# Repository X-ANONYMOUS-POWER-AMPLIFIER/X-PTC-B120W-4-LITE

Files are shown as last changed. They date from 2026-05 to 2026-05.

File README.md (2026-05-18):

# X-PTC-B120W-4-LITE PROTECTION CIRCUIT FOR X-B120W-4-LITE CLASS-B POWER AMPLIFIER MAIN-CIRCUIT

X-PTC-B120W-4-LITE is a protection circuit module for [X-B120W-4-LITE CLASS-B POWER AMPLIFIER MAIN-CIRCUIT](https://github.com/X-ANONYMOUS-POWER-AMPLIFIER/X-B120W-4-LITE/). It provides both open-circuit and short-circuit protection for protecting both side of the power amplifier main-circuit and the loudspeaker. This circuit is designed to be fit on a small size single-sided PCB and for easy to install.

This X-PTC-B120W-4-LITE is designed to work in 12V DC non-symmetrical operating voltage. None of additional operating voltage is needed. The [X-10A42V-DDSB-PSU PSU module](https://github.com/X-ANONYMOUS-POWER-AMPLIFIER/X-10A42V-DDSB-PSU) is applicable to provide operating voltages for powering-up both [X-B120W-4-LITE CLASS-B POWER AMPLIFIER MAIN-CIRCUIT](https://github.com/X-ANONYMOUS-POWER-AMPLIFIER/X-B120W-4-LITE/) module and this X-PTC-B120W-4-LITE protection module. 

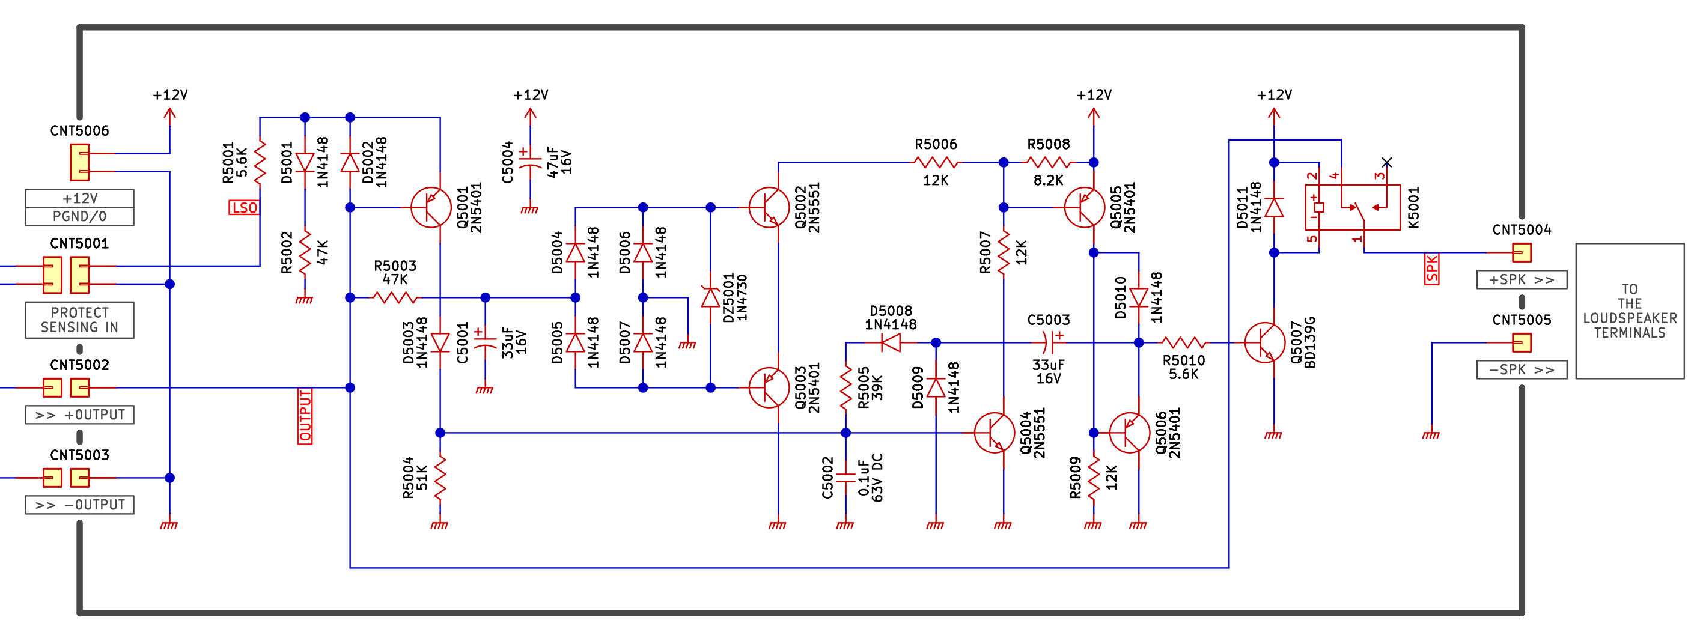
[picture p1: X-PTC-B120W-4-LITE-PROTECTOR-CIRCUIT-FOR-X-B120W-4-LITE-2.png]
X-PTC-B120W-4-LITE schematic diagram


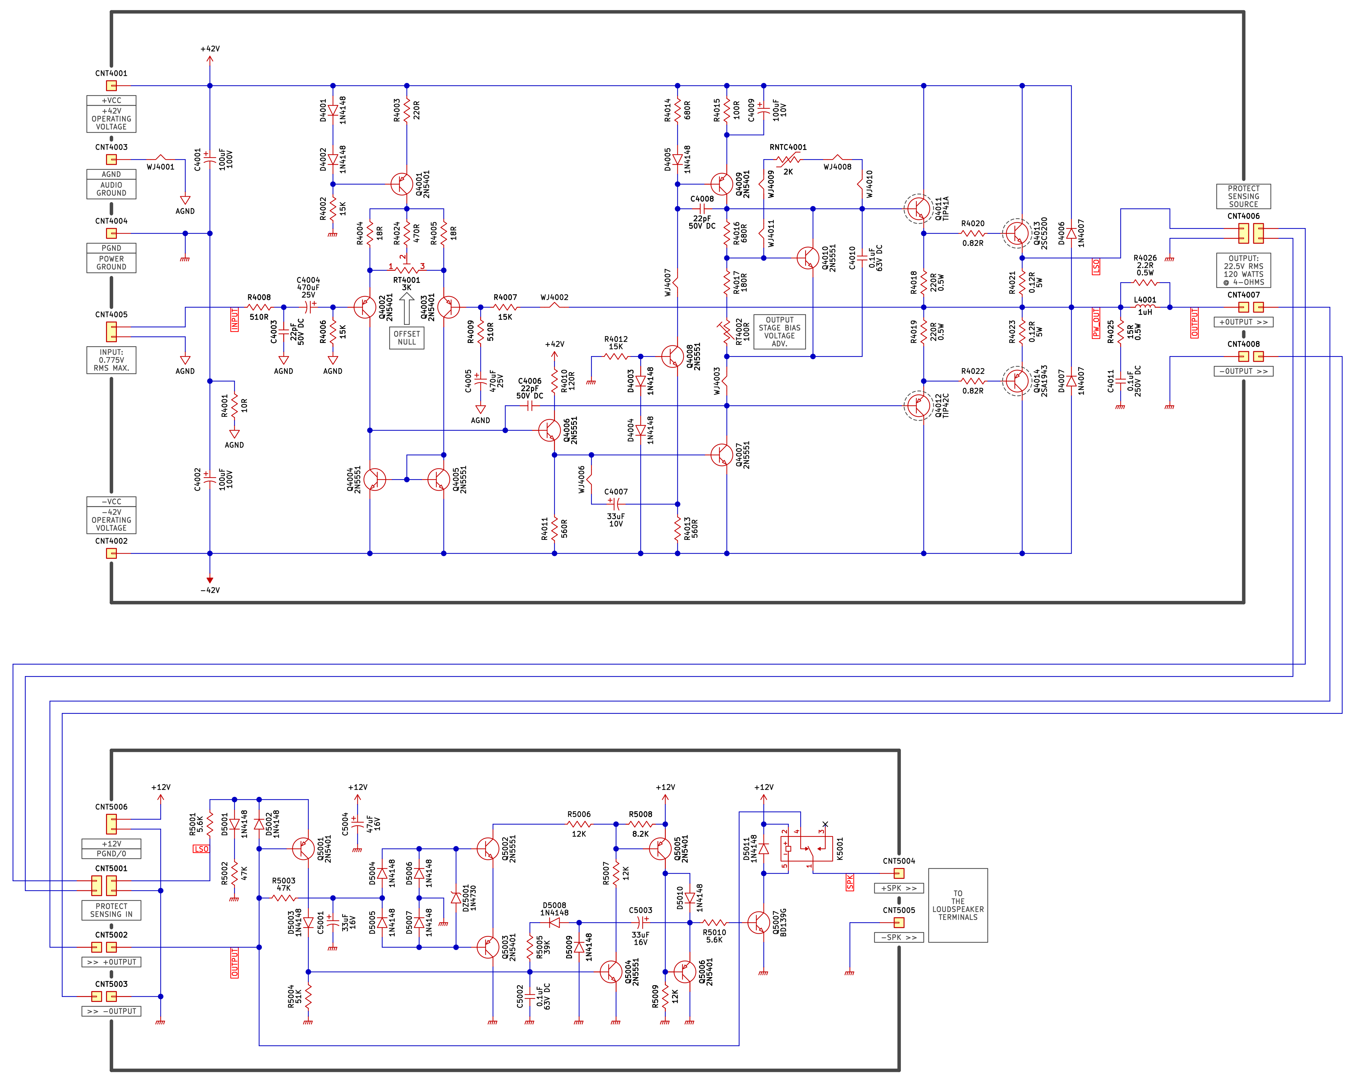
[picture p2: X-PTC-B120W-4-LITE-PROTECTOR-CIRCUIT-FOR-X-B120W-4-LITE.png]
X-PTC-B120W-4-LITE wiring schematic diagram


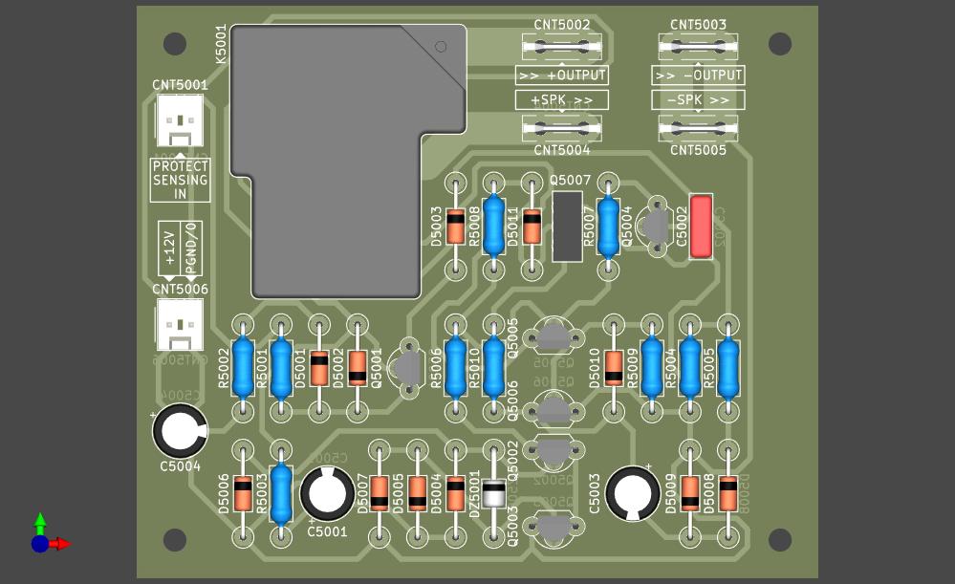
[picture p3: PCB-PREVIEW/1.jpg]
Circuit board preview 1

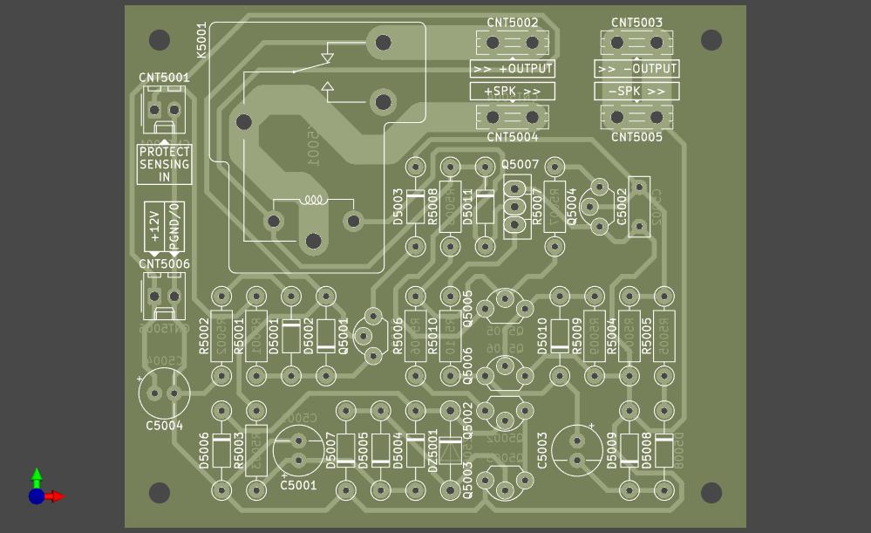
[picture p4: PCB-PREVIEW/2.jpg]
Circuit board preview 2

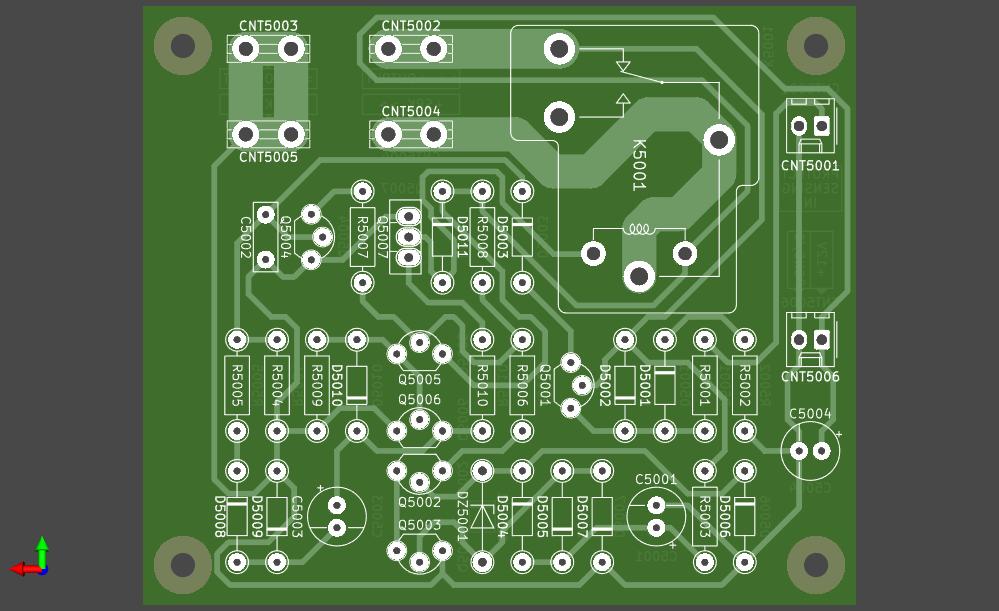
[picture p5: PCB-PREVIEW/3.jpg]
Circuit board preview 3

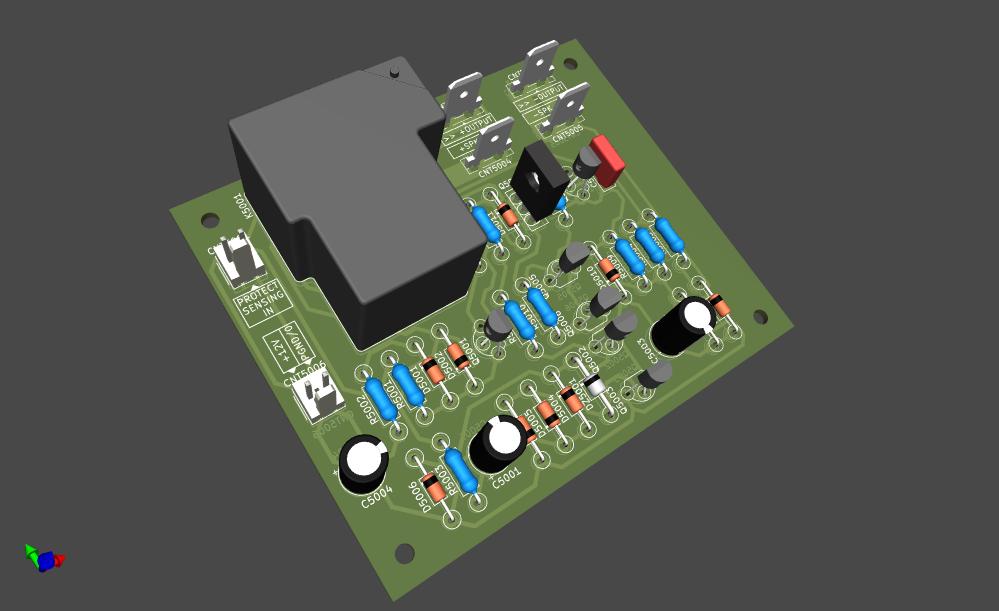
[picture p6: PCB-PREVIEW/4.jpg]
Circuit board preview 4

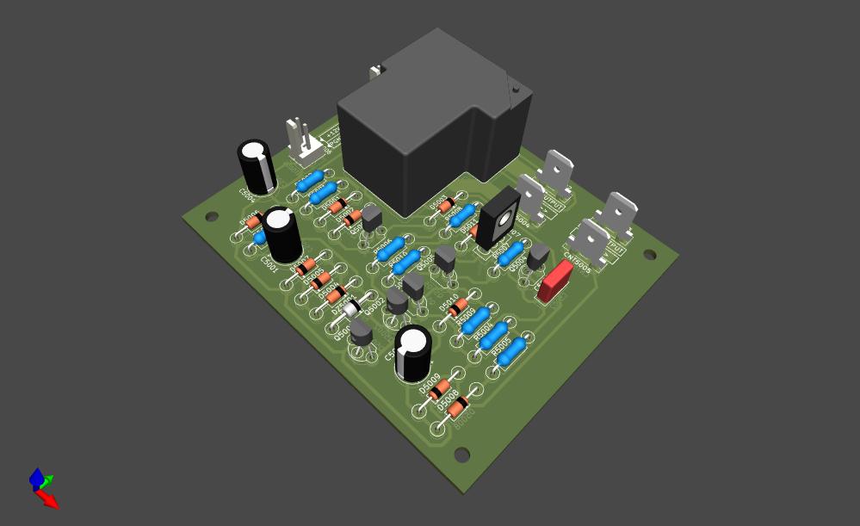
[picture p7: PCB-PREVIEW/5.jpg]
Circuit board preview 5


## License

1. **License Grant**  
The Licensor hereby grants you a worldwide, royalty-free, non-exclusive, perpetual license to use the circuit design for the non-commercial purposes only.
2. **Conditions**  
Attribution: You must provide credit to the original creator when distributing this circuit design.
3. **Disclaimer of Warranty**  
THE DESIGN IS PROVIDED "AS IS". THE LICENSOR MAKES NO WARRANTIES, EXPRESS OR IMPLIED, REGARDING THE DESIGN, INCLUDING BUT NOT LIMITED TO ANY IMPLIED WARRANTIES OF MERCHANTABILITY OR FITNESS FOR A PARTICULAR PURPOSE.
4. **Limitation of Liability**  
IN NO EVENT SHALL THE LICENSOR BE LIABLE FOR ANY DAMAGES, INCLUDING BUT NOT LIMITED TO DIRECT, INDIRECT, INCIDENTAL, OR CONSEQUENTIAL DAMAGES ARISING OUT OF THE USE OF THE DESIGN.

# Design Files Bundle Download

Design files bundle is available for download by follow the URL: [https://github.com/X-ANONYMOUS-POWER-AMPLIFIER/X-PTC-B120W-4-LITE/archive/refs/heads/main.zip](https://github.com/X-ANONYMOUS-POWER-AMPLIFIER/X-PTC-B120W-4-LITE/archive/refs/heads/main.zip)

The main design files of schematic and PCB design are in [KiCad](https://www.kicad.org/) V.9.x format.

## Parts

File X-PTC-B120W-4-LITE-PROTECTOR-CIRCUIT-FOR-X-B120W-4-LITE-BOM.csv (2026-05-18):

Reference | Value | Rating | Description | MFR Number | Manufacturer | Qty
C5001,C5003 | 33uF | 16V | Aluminum Electrolytic Capacitors - Radial Leaded 33uF 16V | ECE-A1CKA330 | Panasonic | 2
C5002 | 0.1uF | 63V DC | Film Capacitors 0.1 uF 63 VDC 5% | MKS2C031001A00JI00 | WIMA | 1
C5004 | 47uF | 16V | Aluminum Electrolytic Capacitors - Radial Leaded 47uF 16V | ECE-A1CKA470 | Panasonic | 1
CNT5001,CNT5006 | 22-27-2021 |  | Headers & Wire Housings 2 POS HEADER | 22-27-2021 | Molex | 2
CNT5002,CNT5003,CNT5004,CNT5005 | 2376582-2 |  | 250 FASTON PCB TAB TPBR | 2376582-2 | TE Connectivity | 4
D5001,D5002,D5003,D5004,D5005,D5006,D5007,D5008,D5009,D5010,D5011 | 1N4148 |  | Small Signal Switching Diodes Small Signal Diode, DO-35, 100V, 0.2A, 175C | 1N4148 | Diotec Semiconductor | 11
DZ5001 | 1N4730 |  | Zener Diodes 3.9 Volt 1.3 Watt | 1N4730A-TAP | Vishay Semiconductors | 1
K5001 | SLA-12VDC-SL-C |  | SUBMINATURE HIGH POWER RELAY 5P | SLA-12VDC-SL-C | Songle Relay | 1
Q5001,Q5003,Q5005,Q5006 | 2N5401 |  | Bipolar Transistors - BJT PNP 160Vcbo 150Vceo 5.0Vebo 600mA 625mW | 2N5401 TIN/LEAD | Central Semiconductor | 4
Q5002,Q5004 | 2N5551 |  | Bipolar Transistors - BJT NPN 180Vcbo 160Vceo 6.0Vebo 600mA 625mW\ | 2N5551 TIN/LEAD | Central Semiconductor | 2
Q5007 | BD139G |  | Bipolar Transistors - BJT 1.5A 80V 12.5W NPN | BD139G | onsemi | 1
R5001,R5010 | 5.6K | 0.25W | Metal Film Resistors - Through Hole 5.6K OHM 1/4W 1% | MFR-25FRE52-5K6 | YAGEO | 2
R5002,R5003 | 47K | 0.25W | Metal Film Resistors - Through Hole 47K OHM 1/4W 1% | MFR-25FRE52-47K | YAGEO | 2
R5004 | 51K | 0.25W | Metal Film Resistors - Through Hole 510 OHM 1/4W 1% | MFR-25FRE52-51K | YAGEO | 1
R5005 | 39K | 0.25W | Metal Film Resistors - Through Hole 39K OHM 1/4W 1% | MFR-25FRE52-39K | YAGEO | 1
R5006,R5007,R5009 | 12K | 0.25W | Metal Film Resistors - Through Hole 12K OHM 1/4W 1% | MFR-25FRE52-12K | YAGEO | 3
R5008 | 8.2K | 0.25W | Metal Film Resistors - Through Hole 8.2K OHM 1/4W 1% | MFR-25FRE52-8K2 | YAGEO | 1

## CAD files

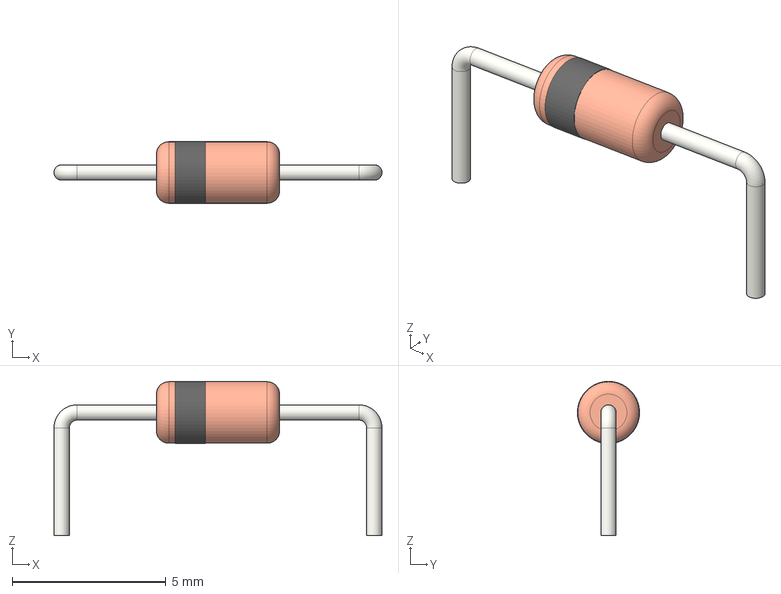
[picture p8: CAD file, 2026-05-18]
3D-FOOTPRINTS/D_DO-35_SOD27_P10.16mm_Horizontal.step
10.7 x 2.02 x 5.01 mm

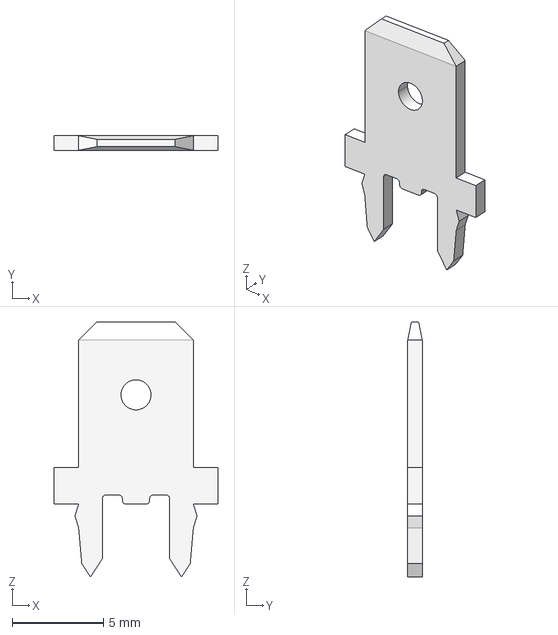
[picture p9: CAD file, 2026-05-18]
3D-FOOTPRINTS/c-2376582-2-a-3d.stp
9.00 x 0.8 x 14.0 mm

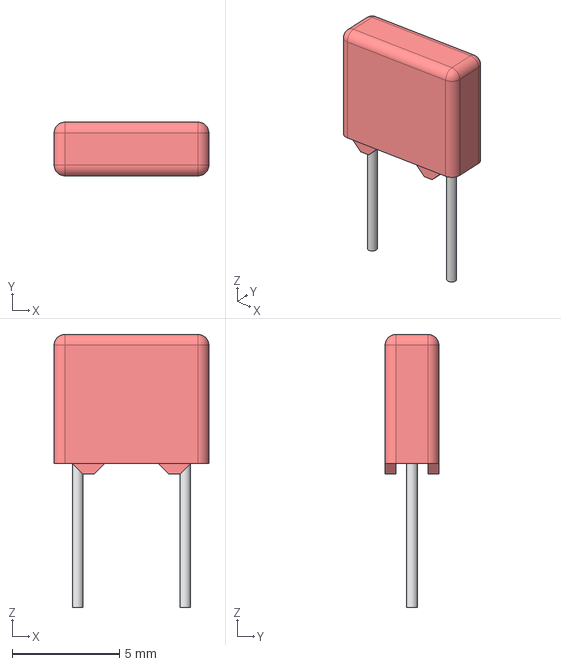
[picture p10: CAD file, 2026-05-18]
3D-FOOTPRINTS/FILM_RED_P500L720W250H650PD50.step
7.20 x 2.50 x 12.7 mm

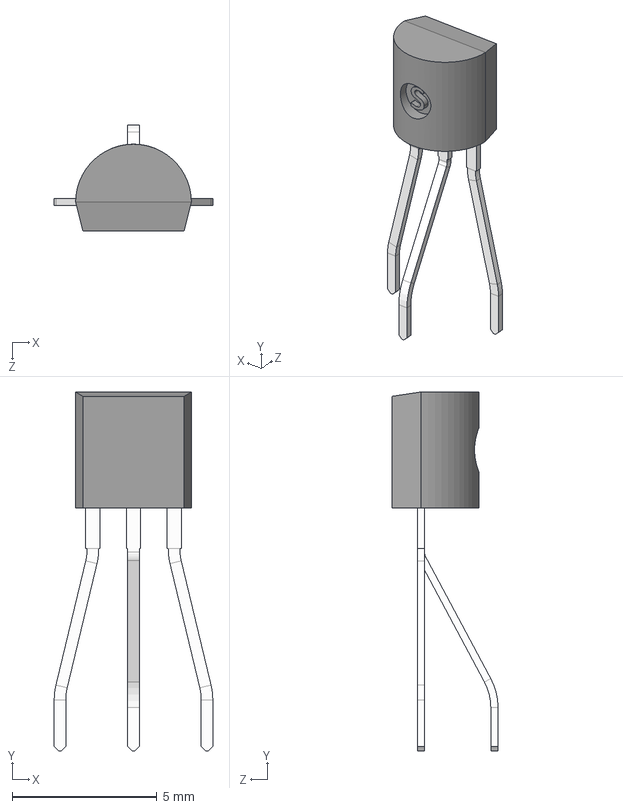
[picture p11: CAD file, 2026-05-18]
3D-FOOTPRINTS/TO-92.STEP
5.48 x 12.4 x 3.66 mm

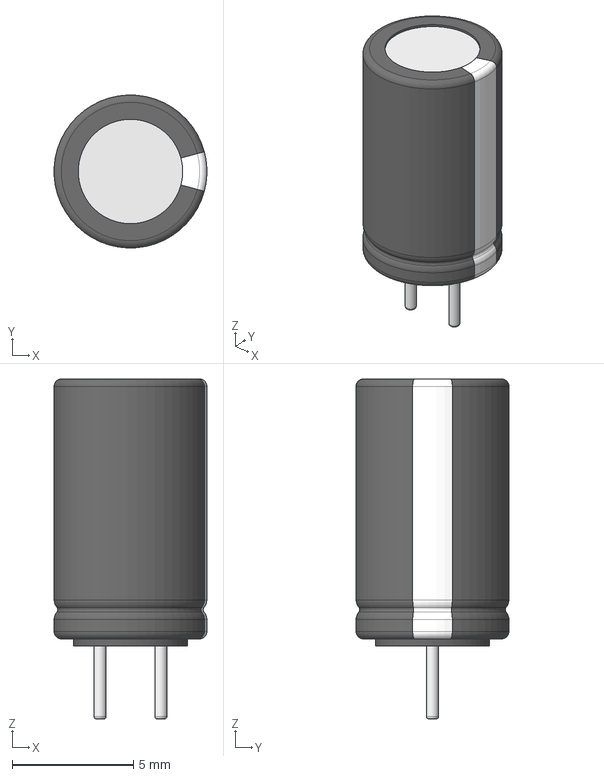
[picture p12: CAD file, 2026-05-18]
3D-FOOTPRINTS/Aluminum_electrolytic_capacitor_radial_D6.3_H11_PinD0.5_Pitch2.5_nominal_black.step
6.29 x 6.30 x 14.0 mm

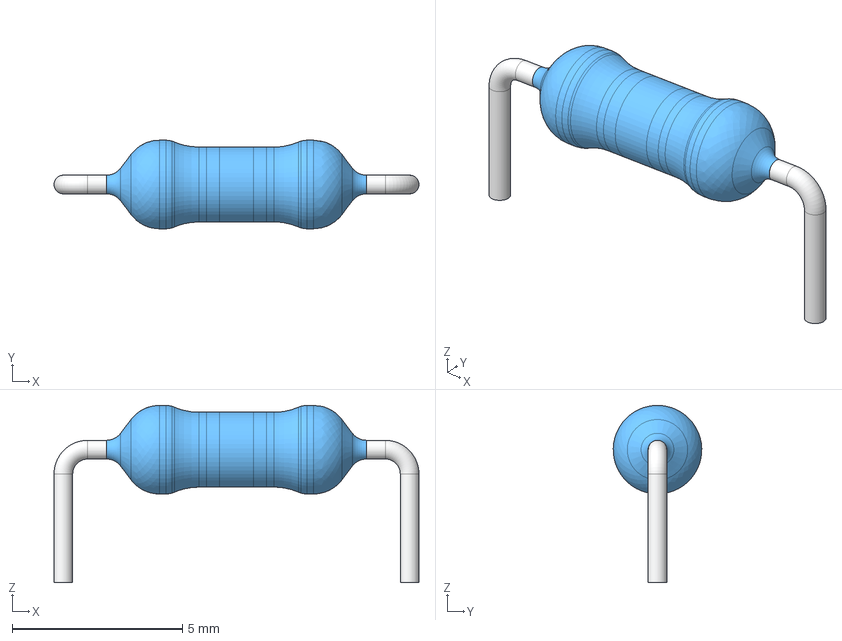
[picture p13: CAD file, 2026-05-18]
3D-FOOTPRINTS/RES-0.25W-H-CF.stp
10.7 x 2.60 x 5.20 mm
RES-0.25W-H-CF
RES-0.25W-H-CF001
RES-0.25W-H-CF002

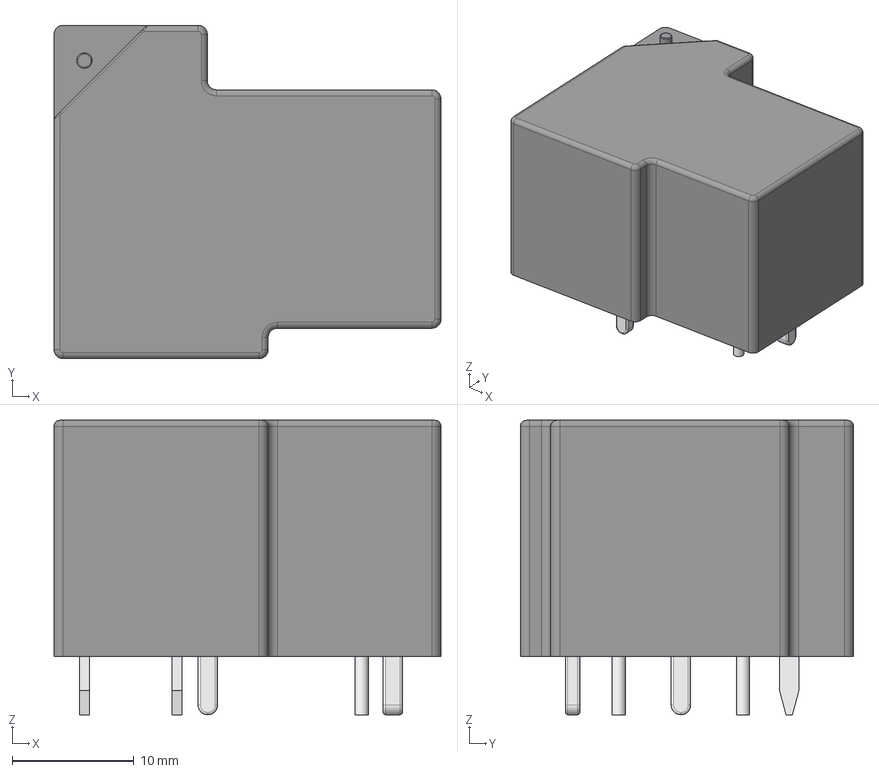
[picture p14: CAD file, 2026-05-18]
3D-FOOTPRINTS/Relay_SPDT_RAYEX-L90.step
31.8 x 27.4 x 24.2 mm
PIN1
PIN002
PIN003
PIN004
PIN006
PIN007

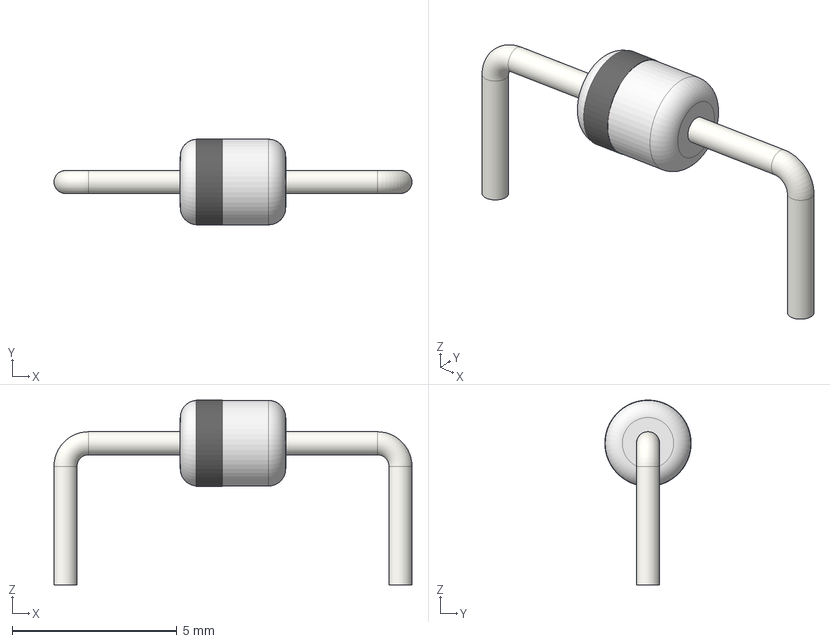
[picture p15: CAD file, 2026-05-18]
3D-FOOTPRINTS/D_T-1_P10.16mm_Horizontal.step
10.9 x 2.62 x 5.61 mm

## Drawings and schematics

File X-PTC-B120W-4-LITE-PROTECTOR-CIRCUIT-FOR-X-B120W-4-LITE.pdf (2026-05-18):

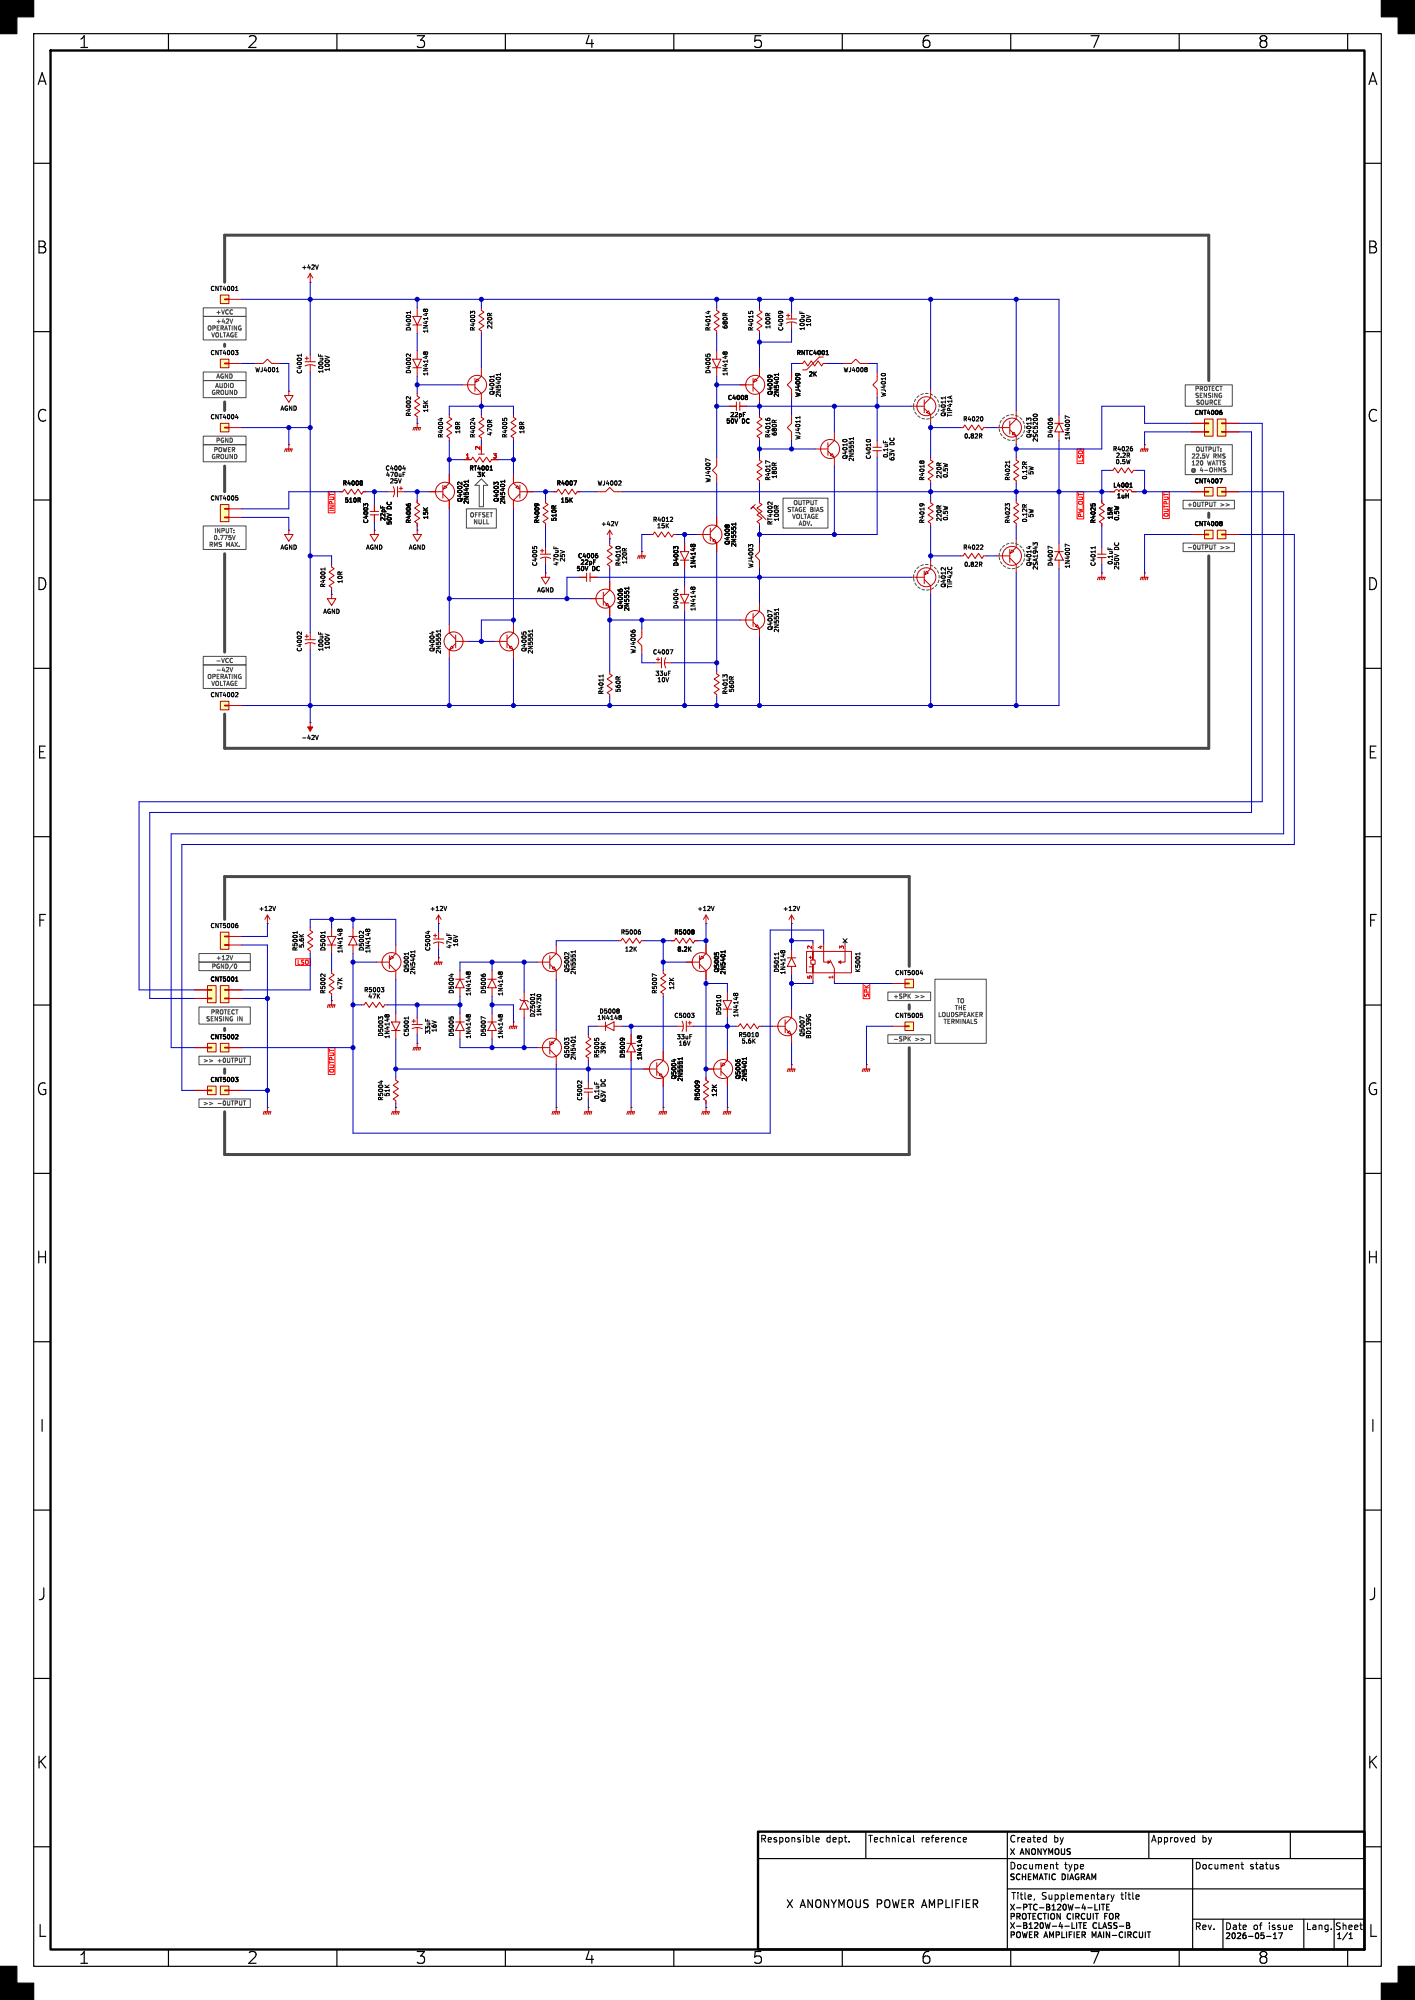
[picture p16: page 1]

X ANONYMOUS

SCHEMATIC DIAGRAM

X-B120W-4-LITE CLASS-B

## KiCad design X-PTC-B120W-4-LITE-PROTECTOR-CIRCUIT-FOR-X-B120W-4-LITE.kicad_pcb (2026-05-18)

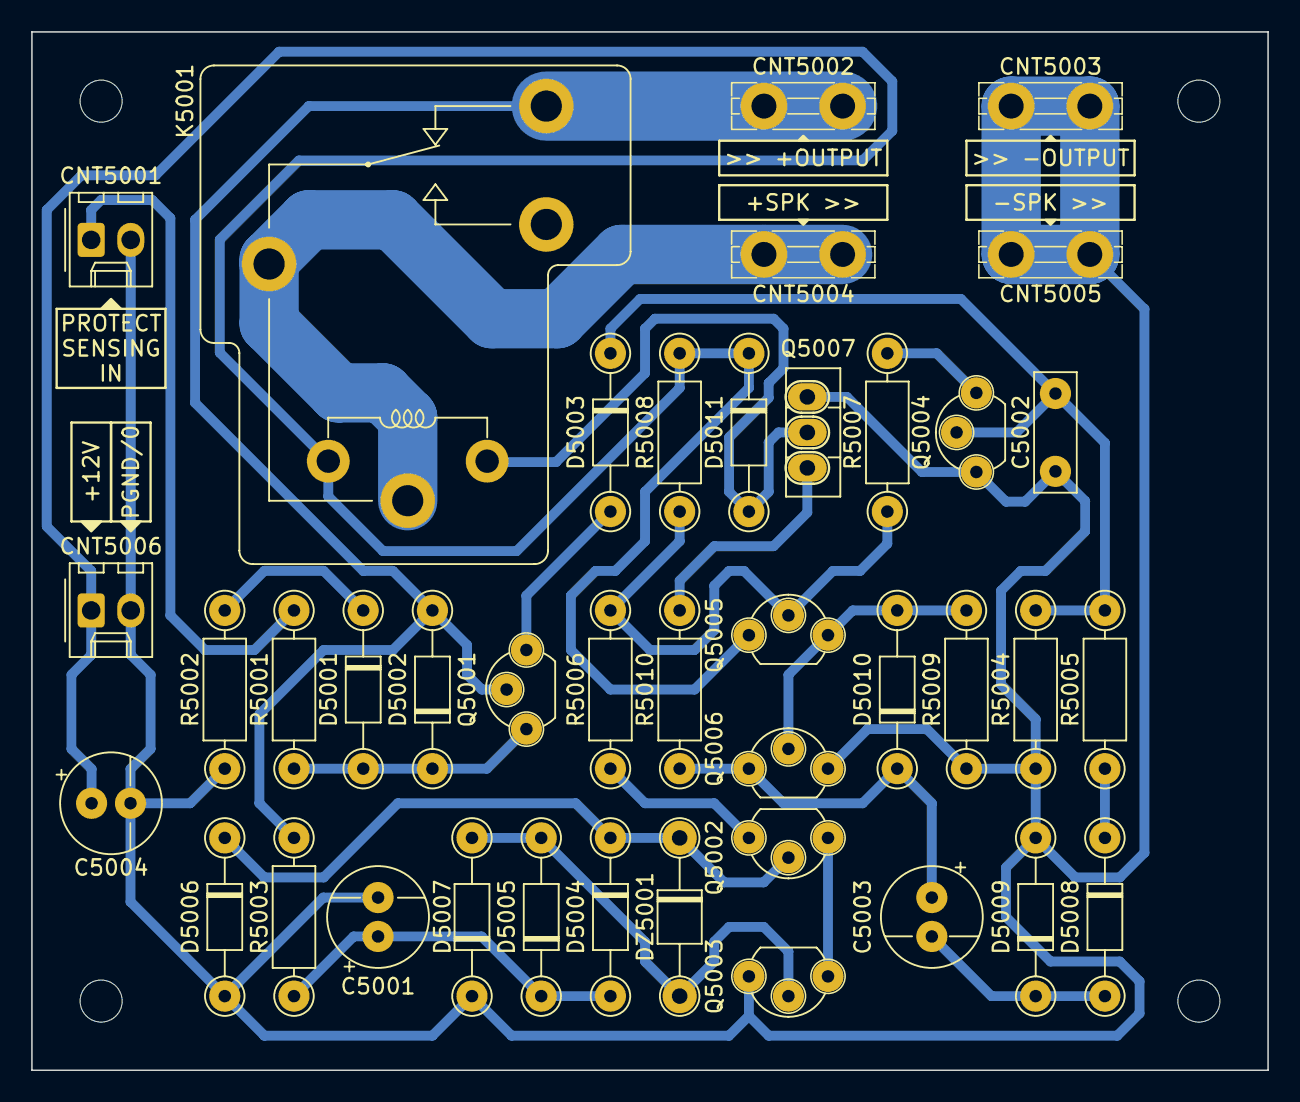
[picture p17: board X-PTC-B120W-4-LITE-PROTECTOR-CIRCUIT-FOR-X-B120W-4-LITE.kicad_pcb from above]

Board: 2 copper layers, 79.4 x 66.7 mm, 40 parts (0 on the bottom side), 22 nets.

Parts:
C5001, C5003: 33uF; CP_Radial_D6.3mm_P2.50mm
C5002: 0.1uF; C_Rect_L7.5mm_W2.5mm_P5.00mm_WIMA_MKS2
C5004: 47uF; CP_Radial_D6.3mm_P2.50mm
CNT5001, CNT5006: 22-27-2021; Molex_KK-254_AE-6410-02A_1x02_P2.54mm_Vertical
CNT5002, CNT5003, CNT5004, CNT5005: 2376582-2; PCB_TAB_250_FASTON_TPBR
D5001, D5002, D5003, D5004, D5005, D5006, D5007, D5008, D5009, D5010, D5011: 1N4148; D_DO-35_SOD27_P10.16mm_Horizontal
DZ5001: 1N4730; D_T-1_P10.16mm_Horizontal
K5001: Relay_SPDT_RAYEX-L90
Q5001, Q5003, Q5005, Q5006: 2N5401; TO-92_3_Wide
Q5002, Q5004: 2N5551; TO-92_3_Wide
Q5007: BD139; TO-126-3_Vertical
R5001, R5010: 5.6K; R_Axial_DIN0207_L6.3mm_D2.5mm_P10.16mm
R5002, R5003: 47K; R_Axial_DIN0207_L6.3mm_D2.5mm_P10.16mm
R5004: 51K; R_Axial_DIN0207_L6.3mm_D2.5mm_P10.16mm
R5005: 39K; R_Axial_DIN0207_L6.3mm_D2.5mm_P10.16mm
R5006, R5007, R5009: 12K; R_Axial_DIN0207_L6.3mm_D2.5mm_P10.16mm
R5008: 8.2K; R_Axial_DIN0207_L6.3mm_D2.5mm_P10.16mm

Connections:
0: C5001.2, C5002.2, C5004.2, CNT5001.2, CNT5003.1, CNT5005.1, CNT5006.2, D5006.2 (A), D5007.1 (K), D5009.2 (A), Q5003.3 (C), Q5004.1 (E), Q5006.3 (C), Q5007.1 (E), R5002.2, R5004.2, R5009.2
+12V: C5004.1, CNT5006.1, D5011.1 (K), K5001.2, Q5005.1 (E), R5008.1
LSO: CNT5001.1, R5001.2
unnamed: D5001.2 (A), D5002.1 (K), Q5001.1 (E), R5001.1
unnamed: D5001.1 (K), R5002.1
unnamed: D5003.2 (A), Q5001.3 (C)
unnamed: C5002.1, D5003.1 (K), Q5004.2 (B), R5004.1, R5005.2
unnamed: C5001.1, D5004.2 (A), D5005.1 (K), R5003.1
unnamed: D5004.1 (K), D5006.1 (K), DZ5001.1 (K), Q5002.2 (B)
unnamed: D5005.2 (A), D5007.2 (A), DZ5001.2 (A), Q5003.2 (B)
unnamed: C5003.2, D5008.2 (A), D5009.1 (K)
unnamed: D5008.1 (K), R5005.1
unnamed: D5010.2 (A), Q5005.3 (C), Q5006.2 (B), R5009.1
unnamed: C5003.1, D5010.1 (K), Q5006.1 (E), R5010.2
unnamed: D5011.2 (A), K5001.5, Q5007.2 (C)
unnamed: Q5002.3 (C), R5006.2
unnamed: Q5002.1 (E), Q5003.1 (E)
unnamed: Q5004.3 (C), R5007.2
unnamed: Q5005.2 (B), R5006.1, R5007.1, R5008.2
unnamed: Q5007.3 (B), R5010.1
OUTPUT: CNT5002.1, D5002.2 (A), K5001.4, Q5001.2 (B), R5003.2
SPK: CNT5004.1, K5001.1
